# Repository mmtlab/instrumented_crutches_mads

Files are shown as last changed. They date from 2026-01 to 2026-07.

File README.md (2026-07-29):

# Instrumented Crutches

This repository contains an instrumented crutches system built on top of [MADS](https://github.com/pbosetti/MADS) (Multi-Agent Distributed System). 

**MADS** is a flexible, plugin-based framework for real-time data acquisition, processing, and distribution. It provides a modular architecture where different components (sources, filters, sinks) can be easily composed to create data processing pipelines. The system uses a publish/subscribe messaging pattern for inter-component communication and supports distributed deployments.

This project implements MADS plugins for collecting and processing data from instrumented crutches, including tip load cells, eye tracking, and coordination between multiple sensors. For more information about MADS, visit the [official documentation](https://mads-net.github.io/).

For the Instrumented Crutches documentation, visit the online [docs](https://mmtlab.github.io/instrumented_crutches_mads/index.html).

*Required MADS version: [2.0.0](https://github.com/pbosetti/MADS/releases/tag/v2.0.0)*
*Required cmake:run "sudo apt install cmake"*

## Installation

First, clone the repository:

```bash
git clone https://github.com/mmtlab/instrumented_crutches_mads.git
cd instrumented_crutches_mads
```

Each agent must be installed separately. See the `README.md` files inside each agent folder for details. 

**Important note**: Not all agents are required on both crutches. Compile only the agents needed for each crutch role:

- **Master crutch** (i.e. right): web_server, coordinator, status_handler, hdf5_writer, tip_loadcell, eye_tracker, ups, ppg
- **Slave crutch** (i.e. left): tip_loadcell, ups, ppg

### Settings file - mads.ini
Check the `mads.ini` configuration (i.e. the tip load cells' scaling factors) and run this command from the repository root if you want to overwrite the existing file:

```bash
sudo cp templates/mads.ini /usr/local/etc/
```

***Note***: provide write permissions to the data folder used by `web_server` and `hdf5_writer` (by default `web_server/data`), otherwise startup can fail.

If needed, fix ownership/permissions with:

```bash
sudo chown -R $USER:$USER ~/instrumented_crutches_mads/web_server/data
chmod -R u+rwX ~/instrumented_crutches_mads/web_server/data
```

### Enable services

Enable services according to the crutch role.

On the master crutch (i.e. right crutch), copy the service files to `/etc/systemd/system`:

```bash
sudo cp templates/mads-broker.service templates/mads-web_server.service templates/mads-coordinator.service templates/mads-status_handler.service templates/mads-hdf5_writer.service templates/mads-eye_tracker.service templates/mads-network_handler.service templates/right/mads-tip_loadcell.service templates/right/mads-handle_loadcell.service templates/right/mads-ups.service templates/right/mads-ppg.service /etc/systemd/system/
```

Then enable them:

```bash
sudo systemctl enable mads-broker.service mads-web_server.service mads-coordinator.service mads-status_handler.service mads-hdf5_writer.service mads-tip_loadcell.service mads-handle_loadcell.service mads-eye_tracker.service mads-network_handler.service mads-ups.service mads-ppg.service
```

On the slave crutch (i.e. left crutch), copy the service file to `/etc/systemd/system`:

```bash
sudo cp templates/left/mads-tip_loadcell.service templates/left/mads-handle_loadcell.service templates/left/mads-ups.service templates/left/mads-ppg.service /etc/systemd/system/
```
Then enable it:

```bash
sudo systemctl enable mads-tip_loadcell.service mads-handle_loadcell.service mads-ups.service mads-ppg.service
```

Use the pre-configured service files in `templates/left` and `templates/right` for the correct crutch side.

For the Python agent, check the paths in the service file and adapt them to the current configuration.

All enabled services start their agents automatically at boot.

### Configure network

On the master crutch Raspberry Pi, create a Wi-Fi hotspot:

```bash
sudo nmcli device wifi hotspot ssid <network-name> password <network-password>
```

On the slave crutch Raspberry Pi, configure the connection to that hotspot and enable auto-connect:

```bash
sudo nmcli connection modify <connection-name> connection.autoconnect yes
sudo nmcli connection up <connection-name>
```

### Configure NTP synchronization

Install chrony by running:

```bash
sudo apt install chrony
```

Copy the configuration file to `/etc/chrony`:

```bash
sudo cp templates/chrony.conf /etc/chrony/
```

Enable and restart the service:

```bash
sudo systemctl enable chrony
sudo systemctl restart chrony
```

Run this NTP configuration on both crutches.

***Important note***: the NTP configuration file (`chrony.conf`) uses `10.42.0.1` as the default server IP.
Check the master crutch hotspot IP address and update the file accordingly before copying it to `/etc/chrony/`.

## Acquisition board case
You can find the acquisition board case STL files in the `templates/case` folder for 3D printing.

## Architecture

```mermaid
---
config:
  layout: elk
  theme: neo-dark
  look: neo
---
flowchart BT
 subgraph master["Master"]
        web_server["Web Server"]
        coordinator["Coordinator"]
        status_handler["Status Handler"]
        hdf5_writer["HDF5 Writer"]
        eye_tracker["Eye Tracker"]
        hdf5[("HDF5 file")]
        m_ups["UPS"]
  end
 subgraph slave["Crutch"]
        s_ups["UPS"]
        s_tip_loadcell["Tip Loadcell"]
        s_handle_loadcell["Handle Loadcell"]
        s_ppg["PPG"]
        s_sync_handler["Sync Handler"]
  end
    web_server -- ws_command --> coordinator
    coordinator -- command --> status_handler & hdf5_writer & eye_tracker
    status_handler -- status --> web_server
    m_ups -- ups --> status_handler
    hdf5_writer -- data --> hdf5
    hdf5_writer -- hdf5_writer --> status_handler
    eye_tracker -- pupil_neon --> status_handler & hdf5_writer
    coordinator -. command .-> s_tip_loadcell & s_handle_loadcell & s_ppg
    s_tip_loadcell -. tip_loadcell .-> status_handler & hdf5_writer
    s_handle_loadcell -. handle_loadcell .-> status_handler & hdf5_writer
    s_ups -. ups .-> status_handler
    s_ppg -. ppg .-> status_handler & hdf5_writer
```

Each instrumented crutch runs on a Raspberry Pi Zero 2 W and uses MADS agents for sensing, control, and communication.
In this architecture, some agents run only on the master crutch, while others run on both crutches.

Master-only services
- **Web Server**: provides the Record/View/Download UI and sends control commands.
- **Coordinator**: receives web commands and orchestrates acquisition lifecycle across agents.
- **Status Handler**: aggregates startup/health/error/shutdown events and publishes system status.
- **HDF5 Writer**: logs incoming topics into structured HDF5 files for each acquisition.
- **Eye Tracker (Pupil Neon)**: manages discovery/connection/recording and publishes sync statistics.

Services deployed on both crutches
- **Tip Loadcell**: acquires axial load from the tip sensor.
- **Handle Loadcell**: acquires multi-channel handle forces.
- **PPG**: acquires photoplethysmography data.
- **UPS**: publishes battery and power metrics.

## Usage

Recommended workflow (Web interface):

1. Power on the master crutch (default: **right**) and wait for services to start.
2. Connect a PC/tablet/smartphone to the master hotspot.
3. Open `http://10.42.0.1:8000` in your browser (the **Record** page).
4. In the **Status** panel, click **Update Datetime** to immediately sync the master date/time.
5. Power on the slave crutch (left): it will auto-connect to the hotspot and sync time via NTP after about 1-2 minutes.
6. In the **Status** panel, verify that the main nodes are reachable (tip/handle/ppg, logger, coordinator; eye-tracker if used).
7. Run calibration in **Calibration** with the **Calibrate** button and check updated values/indicators. **Note:** keep the crutch lifted off the ground and do not press the handle, otherwise the offset calibration will be invalid.
8. (Optional) In the **Eye-tracker** section, click **Connect** and verify the status becomes *Connected*. **Note:** for discovery to work, the Pupil Neon must be paired with its smartphone, and must be connected to the same network as the master crutch.
9. Fill in **Test Configuration** fields (Subject ID, Session ID, Height, Weight, Crutch Height).
10. (Optional) Add notes in **Comments**.
11. (Optional) Click **Condition** and select the current condition.
12. Click **Start** to begin recording.
13. During acquisition, monitor **Status** and confirm services/sensors are in a recording-consistent state.
14. If the condition changes during the test, use **Condition** again. The timestamp of each new condition is recorded.
15. Click **Stop** to end the acquisition.

Note: each acquisition is assigned an incremental ID (shown as `Recording ID`).

After recording:

- **View Data**: select Subject, Session, and Recording to display charts.
- **Download**: download CSV files (`force_ID.csv` and `info_ID.csv`).

Only master (no crutch)
sudo cp templates/mads-broker.service templates/mads-web_server.service templates/mads-coordinator.service templates/mads-status_handler.service templates/mads-hdf5_writer.service templates/mads-eye_tracker.service templates/mads-network_handler.service /etc/systemd/system/

sudo systemctl enable mads-broker.service mads-web_server.service mads-coordinator.service mads-status_handler.service mads-hdf5_writer.service mads-eye_tracker.service mads-network_handler.service

mads-filter hdf5_writer.plugin -b -o folder_path="C:\mirrorworld\instrumented_crutches_mads\web_server\data"

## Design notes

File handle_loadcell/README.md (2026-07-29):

# handle_loadcell plugin for MADS

This is a Filter plugin for [MADS](https://github.com/MADS-NET/MADS). 

<provide here some introductory info>

*Required MADS version: 2.0.0.*

## Supported platforms

Currently, the supported platforms are:

* **Debian** 
* **Windows (debug)**

## Installation

Debian:

```bash
cmake -Bbuild -DCMAKE_INSTALL_PREFIX="$(mads -p)"
cmake --build build
sudo cmake --install build
```

Windows:

```powershell
cmake -Bbuild -DCMAKE_INSTALL_PREFIX="$(mads -p)"  -DRASPBERRYPI_PLATFORM=OFF
cmake --build build --config Release -t install
```

## INI settings

The plugin supports the following settings in the INI file:

```ini
# execution command example:
# mads-filter handle_loadcell -o side=left --dont-block
[handle_loadcell]
sub_topic = ["coordinator"] # power_status is used to adapt the ADC's reference voltage in realtime reading from the "supply_voltage" field
pub_topic = "handle_loadcell"
period = 20
ref_voltage = 4.12
adc1_rate = 9 # ADS1263 rate index, default 9 = 1200 SPS, but raspberry can reach maximum 100Hz
side = "unknown" # used to select scaling factors
health_status_period = 500 # ms
# Adjust the input number with the connected loadcell's label
# Default is:
#  IN0, IN1, IN2, IN3, IN4, IN5, IN6, IN7 
# "up_front", "up_back", "right_front", "right_back", "left_front", "left_back","down_front", "down_back"
input_map = [[0, "up_front"], [1, "up_back"], [2, "right_front"], [3, "right_back"], [4, "left_front"], [5, "left_back"], [6, "down_front"], [7, "down_back"]]

[handle_loadcell.range_map]
left = [[0, 500.0], [1, 500.0], [2, 50.0], [3, 50.0], [4, 50.0], [5, 50.0], [6, 50.0], [7, 50.0]] # IN0, IN1, IN2, IN3, IN4, IN5, IN6, IN7
right = [[0, 500.0], [1, 500.0], [2, 50.0], [3, 50.0], [4, 50.0], [5, 50.0], [6, 50.0], [7, 50.0]] # IN0, IN1, IN2, IN3, IN4, IN5, IN6, IN7
```

All settings are optional; if omitted, the default values are used.

When `health_status_period` elapses, the plugin also publishes a `perf` block with:

- `adc_read_ms`: time spent in `ADS1263_GetAll(...)`
- `process_ms`: duration of a full `process()` call
- `cycle_ms`: time between successive completed `process()` calls
- `adc1_rate`: configured ADS1263 data rate index
- `channels`: number of channels read each cycle

## Executable demo

<Explain what happens if the test executable is run>

---

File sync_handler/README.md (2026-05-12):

# sync_handler plugin for MADS

This is a Filter plugin for [MADS](https://github.com/MADS-NET/MADS). 

<provide here some introductory info>

*Required MADS version: 2.0.0.*

## Supported platforms

Currently, the supported platforms are:

* **Debian** 

## Installation

Debian:

```bash
cmake -Bbuild -DCMAKE_INSTALL_PREFIX="$(mads -p)"
cmake --build build
sudo cmake --install build
```

## INI settings

The plugin supports the following settings in the INI file:

```ini
# execution command example:
# mads-filter sync_handler -o side=left -s tcp://10.42.0.1:9092
[sync_handler]
sub_topic = ["coordinator"]
pub_topic = "sync_handler"
health_status_period = 1000 # ms
queue_size = 1
```

All settings are optional; if omitted, the default values are used.

Operational constraints:

* `queue_size` must be set to `1`.
* The `-b` argument is not needed, because the synchronization check is only performed when a message is received from the `coordinator` topic.
* The NTP server and the `coordinator` must run on the same device, so the timestamp comparison is performed against a single local time source.

## Executable demo

<Explain what happens if the test executable is run>

---

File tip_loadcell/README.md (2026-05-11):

# loadcell plugin for MADS

This is a Filter plugin for [MADS](https://github.com/pbosetti/MADS). 

<provide here some introductory info>

*Required MADS version: [2.0.0](https://github.com/pbosetti/MADS/releases/tag/v2.0.0)*

## Supported platforms

Currently, the supported platforms are:

* **Debian** 
* **Windows**

## Installation

Install the HX711's library ([HX711](https://github.com/mrcghidelli/hx711.git))

```bash
sudo apt-get install -y liblgpio-dev

git clone https://github.com/mrcghidelli/hx711.git
cd hx711

make && sudo make install
```
You may need to run ldconfig at this point if you attempt to compile a program and libhx711 is not found.

Then install the MADS agent.

Raspberry:

```bash
cmake -Bbuild -DCMAKE_INSTALL_PREFIX="$(mads -p)"
cmake --build build
sudo cmake --install build
```

Windows (debug and develop):

```powershell
cmake -Bbuild -DCMAKE_INSTALL_PREFIX="$(mads -p)" -DRASPBERRYPI_PLATFORM=OFF
cmake --build build --config Release -t install
```

## INI settings

The plugin supports the following settings in the INI file:

```ini
# execution command example:
# mads-filter tip_loadcell.plugin -o side=left --dont-block
[tip_loadcell]
sub_topic = ["coordinator"]
pub_topic = "tip_loadcell"
datapin = 6
clockpin = 26
period = 5 # it must be lower than 10 ms otherwise the HX711 will enter power down mode, which causes a delay of ~100 ms when reading the next value (it wakes up and takes ~100 ms to stabilize the readings)
side = "unknown" # used to select scaling factor
health_status_period = 500 # ms

[tip_loadcell.scaling]
left = 1.0 # debug value
right = 1.2 # debug value

```

All settings are optional; if omitted, the default values are used.

**Note:** The HX711 sampling frequency must remain above 80 Hz to prevent power-down mode. We recommend setting the period to 5 ms.

## Executable demo

<Explain what happens if the test executable is run>

---

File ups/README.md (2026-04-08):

# UPS for MADS

This is a Python agent for [MADS](https://github.com/MADS-NET/MADS). 

<provide here some introductory info>

*Required MADS version: 2.0.0.*

## Supported platforms

Currently, the supported platforms are:

* **Debian / Raspberry Pi OS (I2C required)**

## Setup

```bash
# Enable I2C on Raspberry Pi first (raspi-config -> Interface Options -> I2C)

# System packages (Raspberry Pi / Debian)
sudo apt-get update
sudo apt-get install -y python3-pip python3-smbus i2c-tools

# Create and activate venv (recommended)
python -m venv venv
source venv/bin/activate  # On Windows: venv\Scripts\activate

# Install dependencies
pip install -r requirements.txt
```

**Dependencies:**
- smbus (provided by `python3-smbus`) or `smbus2` via pip fallback

## Run example

```bash
python ups.py -o side=right
```

Add `-s tcp:\\<broker-ip>:9092` to connect to a remote broker (default is `tcp:\\localhost:9092`).

The agent connects to MADS broker and publishes every `health_status_period` ms on `pub_topic`.
Each published message contains:

- `voltage`
- `current`
- `power`
- `percent`
- `remaining_battery_time`

`remaining_battery_time` is estimated with a linear fit over the last 60 seconds of battery percentage history, and is expressed in seconds. If the trend is flat/rising, the value is `null`.

## INI settings

The plugin supports the following settings in the INI file:

```ini
[ups]
pub_topic = "ups"
health_status_period = 500 # ms
i2c_bus = 1
i2c_address = 67 # decimal for 0x43
battery_empty_voltage = 3.0
battery_full_voltage = 4.2
```

`health_status_period` controls the publish period. Battery percentage and remaining time use `battery_empty_voltage` and `battery_full_voltage` for normalization.

All settings are optional; if omitted, the default values are used.

## Executable demo

<Explain what happens if the test executable is run>

---

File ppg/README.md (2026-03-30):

# UPS HAT for MADS

This is a Python agent for [MADS](https://github.com/MADS-NET/MADS). 

The source code to acquire from the MAX 30100 has been get from https://github.com/mfitzp/max30100.git

<provide here some introductory info>

*Required MADS version: 2.0.0.*

## Supported platforms

Currently, the supported platforms are:

* **Debian / Raspberry Pi OS (I2C required)**

## Setup

```bash
# Enable I2C on Raspberry Pi first (raspi-config -> Interface Options -> I2C)

# System packages (Raspberry Pi / Debian)
sudo apt-get update
sudo apt-get install -y python3-smbus i2c-tools

# Create and activate venv (recommended)
python -m venv venv
source venv/bin/activate  # On Windows: venv\Scripts\activate

# Install dependencies
pip install -r requirements.txt
```

**Dependencies:**
- smbus (provided by `python3-smbus`) or `smbus2` via pip fallback

## Run

```bash
python ppg.py
```

Add `-s tcp:\\<broker-ip>:9092` to connect to a remote broker (default is `tcp:\\localhost:9092`).

## INI settings

The plugin supports the following settings in the INI file:

```ini
[ppg]
sub_topic = ["coordinator"]
pub_topic = "ppg"
health_status_period = 500 # ms
period = 10 # ms, 100 Hz
side = "unknown"
```

All settings are optional; if omitted, the default values are used.

---

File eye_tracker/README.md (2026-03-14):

# Eye Tracker for MADS

This is a Python agent for [MADS](https://github.com/pbosetti/MADS) that integrates with Pupil Labs Neon eye trackers.

*Required MADS version: [2.0.0](https://github.com/pbosetti/MADS/releases/tag/v2.0.0)*

## Description

The `pupil_neon` agent enables data acquisition from Pupil Labs Neon eye tracking devices. It handles device discovery, connection management, recording control, and real-time synchronization monitoring.

## Features

- **Automatic Device Discovery**: Discovers Pupil Labs Neon devices on the local network
- **Recording Control**: Start/stop recordings with template-based metadata (subject ID, session ID, acquisition ID)
- **Condition Events**: Send labeled condition markers during recording for experimental protocols
- **Time Synchronization**: Estimates and publishes time offset and round-trip latency statistics
- **Health Monitoring**: Continuous connection health checks and status reporting
- **Agent Status Tracking**: Reports connection state and errors via MADS publish/subscribe

## Agent States

- **STARTUP**: Agent initializing
- **IDLE**: Connected to MADS, waiting for commands (no device connected)
- **CONNECTED**: Device connected and ready for recording
- **RECORDING**: Currently recording data
- **SHUTDOWN**: Agent shutting down

## Supported Commands

Commands are received via MADS topic and processed based on agent state:

| Command | State | Action |
|---|---|---|
| `pupil_neon_connect` | IDLE | Discover and connect to Pupil Neon device |
| `pupil_neon_disconnect` | CONNECTED, RECORDING | Stop recording (if active) and disconnect device |
| `start` | CONNECTED | Fill device template and start recording |
| `stop` | RECORDING | Stop recording and save data |
| `condition` | RECORDING | Send labeled condition marker (e.g., "trial_A.begin") |

## Published Data

The agent publishes the following information to the MADS topic:

```json
{
  "agent_status": "idle|connected|recording",
  "error": "error message (if any)",
  "time_offset_ms_mean": 0.5,
  "time_offset_ms_std": 0.2,
  "time_offset_ms_median": 0.4,
  "roundtrip_duration_ms_mean": 15.3,
  "roundtrip_duration_ms_std": 2.1,
  "roundtrip_duration_ms_median": 14.9
}
```

- **agent_status**: Current operational state
- **error**: Error message if connection is lost or operation fails
- **time_offset_ms_***: Estimated clock synchronization offset in milliseconds (mean, std, median)
- **roundtrip_duration_ms_***: Network round-trip latency statistics in milliseconds

## INI Settings

```ini
[pupil_neon]
sub_topic = ["coordinator"]
pub_topic = "pupil_neon"
health_status_period = 500 # ms
```

## Setup

```bash
# Create and activate venv (recommended)
python -m venv venv
source venv/bin/activate  # On Windows: venv\Scripts\activate

# Install dependencies
pip install -r requirements.txt
```

**Dependencies:**
- pupil-labs-realtime-api

## Run

```bash
python pupil_neon.py
```

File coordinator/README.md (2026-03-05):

# coordinator plugin for MADS

This is a Filter plugin for [MADS](https://github.com/pbosetti/MADS). 

*Required MADS version: [2.0.0](https://github.com/pbosetti/MADS/releases/tag/v2.0.0)*

## Supported platforms

Currently, the supported platforms are:

* **Debian** 
* **Windows (debug only)**

## Installation

Debian:

```bash
cmake -Bbuild -DCMAKE_INSTALL_PREFIX="$(mads -p)"
cmake --build build
sudo cmake --install build
```

Windows (debug only):

```powershell
cmake -Bbuild -DCMAKE_INSTALL_PREFIX="$(mads -p)" -DRASPBERRYPI_PLATFORM=OFF
cmake --build build --config Release -t install
```

## INI settings

The plugin supports the following settings in the INI file:

```ini
# execution command example:
# mads-filter coordinator -b
[coordinator]
sub_topic = ["ws_command"]
pub_topic = "coordinator"
period = 10
health_status_period = 500 # ms
```

**Note**: This agent must run in non-blocking mode. Use the `-b` or `--dont-block` argument when running it.

---

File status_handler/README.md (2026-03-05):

# error_handler plugin for MADS

This is a Filter plugin for [MADS](https://github.com/pbosetti/MADS). 

*Required MADS version: [2.0.0](https://github.com/pbosetti/MADS/releases/tag/v2.0.0)*

## Supported platforms

Currently, the supported platforms are:

* **Debian**
* **Windows (debug)**

## Installation

Debian:

```bash
cmake -Bbuild -DCMAKE_INSTALL_PREFIX="$(mads -p)"
cmake --build build
sudo cmake --install build
```

Windows (debug):

```powershell
cmake -Bbuild -DCMAKE_INSTALL_PREFIX="$(mads -p)"
cmake --build build --config Release -t install
```

## INI settings

The plugin supports the following settings in the INI file:

```ini
# execution command example:
# mads-filter status_handler
[status_handler] 
sub_topic = ["agent_event", "coordinator", "hdf5_writer", "tip_loadcell", "handle_loadcell", "imu", "pupil_neon"] # add other relevant topics to monitor (startup events, error events and shutdown events from all agents are automatically published to "agent_event" topic)
pub_topic = "status"
unreachable_agent_timeout = 3000 # ms
debug = false

```

---

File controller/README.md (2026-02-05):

# controller plugin for MADS

This is a Filter plugin for [MADS](https://github.com/MADS-NET/MADS). 

<provide here some introductory info>

*Required MADS version: 1.4.0.*

## Supported platforms

Currently, the supported platforms are:

* **Linux** 
* **MacOS**
* **Windows**

## Installation

Linux and MacOS:

```bash
cmake -Bbuild -DCMAKE_INSTALL_PREFIX="$(mads -p)"
cmake --build build
sudo cmake --install build
```

Windows:

```powershell
cmake -Bbuild -DCMAKE_INSTALL_PREFIX="$(mads -p)"
cmake --build build --config Release
cmake --install build --config Release
```

## INI settings

The plugin supports the following settings in the INI file:

```ini
[controller]
# Describe the settings available to the plugin
```

All settings are optional; if omitted, the default values are used.

## Executable demo

<Explain what happens if the test executable is run>

---

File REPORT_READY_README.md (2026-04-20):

# Instrumented Crutches - Test and System Report Template

Document version: 1.0
Project: Instrumented Crutches (MADS-based)

===============================================================================
1) DOCUMENT CONTROL
===============================================================================
Report title:
Author:
Date:
Revision:
Test environment (lab/clinical):
Related ticket/issue references:

===============================================================================
2) EXECUTIVE SUMMARY
===============================================================================
This document describes the Instrumented Crutches system, including software
architecture, installation procedure, operational workflow, and data acquisition
session results. The system is based on the MADS framework and a master/slave
architecture over two instrumented crutches.

Session objective:
Main outcome:
Key critical issues:
Next actions:

===============================================================================
3) SYSTEM OVERVIEW
===============================================================================
The system acquires biomechanical and physiological data from two instrumented
crutches, with optional eye-tracking integration (Pupil Neon) for combined
movement and visual-behavior analysis.

Key points:
- Real-time multi-sensor acquisition.
- Centralized coordination through MADS broker.
- Structured HDF5 logging.
- Web interface for start/stop, calibration, annotations, and status.

Roles:
- Master crutch (typically right): hosts web server, coordinator, status handler,
  hdf5 writer, eye tracker, and part of the sensors.
- Slave crutch (typically left): acquires and publishes sensor streams.

Communication:
- Publish/subscribe over MADS topics.

===============================================================================
4) TECHNICAL ARCHITECTURE
===============================================================================
Main agents (master only):
- web_server: UI and API for session management.
- coordinator: command orchestration and acquisition state management.
- status_handler: agent status/health aggregation.
- hdf5_writer: data persistence to HDF5 files.
- pupil_neon: eye-tracker integration.

Agents on both crutches:
- tip_loadcell: tip force acquisition.
- handle_loadcell: multi-channel handle force acquisition.
- ppg: photoplethysmography signal (IR/RED).
- ups: power and battery telemetry.

Simplified data flow:
1. web_server sends commands.
2. coordinator propagates commands to agents.
3. sensors publish streams.
4. status_handler produces aggregated system status.
5. hdf5_writer stores streams into HDF5.

===============================================================================
5) INSTALLATION SUMMARY
===============================================================================
Minimum prerequisites:
- Raspberry Pi Zero 2 W (or equivalent)
- Raspberry Pi OS
- MADS >= 2.0.0
- Python >= 3.9

Main setup steps:
1. Clone the repository.
2. Install/build required agents for master and slave.
3. Configure mads.ini.
4. Install and enable systemd services.
5. Configure network (master hotspot + slave auto-connect).
6. Configure time synchronization (chrony) on both nodes.

Important operational notes:
- Verify write permissions on the data folder used by web_server/hdf5_writer.
- Verify hotspot IP consistency with NTP configuration.
- Use side-specific service templates (left/right).

===============================================================================
6) USER OPERATION WORKFLOW
===============================================================================
Recommended workflow:
1. Power on master and wait for services startup.
2. Connect client device (PC/tablet/smartphone) to master hotspot.
3. Open the Record page (default: http://10.42.0.1:8000).
4. Run Update Datetime from the Status panel.
5. Power on slave and wait for network/time alignment.
6. Verify reachability of main nodes in Status.
7. Run calibration (crutch lifted, no force on handle).
8. (Optional) Connect eye-tracker.
9. Fill Test Configuration.
10. (Optional) Add comments and condition.
11. Start recording (Start).
12. Monitor system status during test.
13. Update condition if needed during acquisition.
14. Stop recording (Stop).
15. Visualize/download post-session data.

Post-recording outputs:
- Data visualization.
- CSV export (force_ID.csv, info_ID.csv).
- Session HDF5 file.

===============================================================================
7) DATA AND OUTPUTS
===============================================================================
Main data types:
- Tip loadcell forces.
- Handle loadcell forces (multi-channel).
- PPG (IR/RED).
- Agent status and health.
- UPS telemetry (voltage/current/power/percent/remaining time).
- Session events/metadata (condition, comments, session IDs).

Persistence format:
- HDF5 with topic/keypath-based structure.

Session identifiers:
- Subject ID
- Session ID
- Incremental Recording ID

===============================================================================
8) TEST SESSION DETAILS (TO BE FILLED)
===============================================================================
Subject ID:
Session ID:
Recording ID:
Master side:
Slave side:
Eye-tracker used (YES/NO):
Operator:
Test duration:

Configured parameters:
- Subject height:
- Subject weight:
- Crutch height:
- Initial condition:

Event timeline:
- T0 system startup:
- T1 calibration:
- T2 start recording:
- T3 condition change (if any):
- T4 stop recording:

===============================================================================
9) HEALTH CHECK RESULTS
===============================================================================
Agent reachability outcome:
- coordinator:
- status_handler:
- hdf5_writer:
- tip_loadcell (master/slave):
- handle_loadcell (master/slave):
- ppg (master/slave):
- ups (master/slave):
- pupil_neon (if used):

Detected errors:
Applied mitigations:
Final health outcome:

===============================================================================
10) ISSUES, RISKS, AND LIMITATIONS
===============================================================================
Open issues:
1.
2.
3.

Known risks:
- Time drift if NTP is not correctly aligned.
- Invalid calibration if performed under applied load.
- Hotspot network instability in noisy radio environments.

Session limitations:

===============================================================================
11) CONCLUSIONS
===============================================================================
Final summary:

Decision (PASS/FAIL/PASS WITH NOTES):

Recommended follow-up actions:
1.
2.
3.

===============================================================================
12) APPENDIX - QUICK REFERENCES
===============================================================================
Project documentation:
- docs/index.html
- docs/installation.html
- docs/usage.html
- docs/architecture.html

Agent READMEs:
- web_server/README.md
- coordinator/README.md
- status_handler/README.md
- hdf5_writer/README.md
- eye_tracker/README.md
- tip_loadcell/README.md
- handle_loadcell/README.md
- ppg/README.md
- ups/README.md

===============================================================================
END OF TEMPLATE
===============================================================================

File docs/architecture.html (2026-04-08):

# System Architecture

The system is organized around two crutches connected through the MADS broker. The master crutch hosts the control and logging services, while both crutches run the sensing agents that publish data to the network.

## Overview

Each crutch is based on a Raspberry Pi Zero 2 W and runs a small set of MADS agents. The master side coordinates the acquisition workflow, stores data, and exposes the web interface. The slave side focuses on local sensing and publishes the same acquisition streams so the master can merge them into a single recording.

## Role Split

- Master-only services: Web Server, Coordinator, Status Handler, HDF5 Writer, Eye Tracker.
- Services on both crutches: Tip Loadcell, Handle Loadcell, PPG, UPS.

## System Diagram

Instrumented Crutches architecture diagram

Open diagram in a new tab

## Data Flow

The Web Server issues commands to the Coordinator through the MADS broker. The Coordinator drives the sensing agents, the Status Handler reports the live health of the system, and the HDF5 Writer persists the data streams that are later consumed by the visualization and download tools.

## Agent Details

Each agent is shown in its own transposed table for readability.

### Master-only agents

web_server
Agent type | Filter
Role | FastAPI backend and UI host. Manages acquisitions, test metadata, comments, conditions, plotting, and CSV download.
Sub topics | status
Pub topics | ws_command
JSON output format | {"command": "...", ...} with allowed values for command: start, stop, set_offset, get_agents_status, datetime_update, condition, pupil_neon_connect, pupil_neon_disconnect

coordinator
Agent type | Filter
Role | Command router and state gate. Validates transitions and forwards normalized commands to all agents.
Sub topics | ws_command
Accepted command | start, stop, condition, datetime_update get_agents_status, set_offset pupil_neon_connect, pupil_neon_disconnect
Pub topics | coordinator
JSON output format | Command: {"command":..., "id"?:n, "label"?:s, "subject_id"?:n, "session_id"?:n} Heartbeat: {"agent_status":"idle|recording"}

status_handler
Agent type | Filter
Role | Status aggregator and normalizer. It merges agent events and health messages into a single stream and marks agents unreachable after a timeout.
Sub topics | agent_event coordinator ups hdf5_writer tip_loadcell handle_loadcell ppg pupil_neon
Accepted command | get_agents_status
Pub topics | status
JSON output format | {"status":{"source","level","status","message","side"?}}

hdf5_writer
Agent type | Filter
Role | HDF5 logger. During recording, appends configured keypaths to topic groups and finalizes files on stop.
Sub topics | coordinator tip_loadcell handle_loadcell ppg pupil_neon ups
Accepted command | start stop
Pub topics | hdf5_writer
JSON output format | Heartbeat: {"agent_status":"idle|recording"}

pupil_neon
Agent type | Filter
Role | Pupil Neon integration: device discovery/connection, recording control, condition events, and time-sync metrics.
Sub topics | coordinator
Accepted command | pupil_neon_connect start condition stop pupil_neon_disconnect
Pub topics | pupil_neon
JSON output format | Heartbeat: {"agent_status":...,"error"?:...} Sync: time_offset_ms_*, roundtrip_duration_ms_*, (*mean, median, and std)

### Agents deployed on both crutches

tip_loadcell
Agent type | Filter
Role | HX711-based tip force acquisition with side-specific scale and offset handling.
Sub topics | coordinator
Accepted command | start stop set_offset
Pub topics | tip_loadcell
JSON output format | Recording: {"force":n,"side":"left|right"} Heartbeat: {"agent_status":"idle|recording","side":"left|right"} Offset: {"info":{"offset":{"value":n,"test":n}},"side":"left|right"}

handle_loadcell
Agent type | Filter
Role | 8-channel ADS1263 handle-force acquisition with channel map, range conversion, and offset calibration.
Sub topics | coordinator
Accepted command | start stop set_offset
Pub topics | handle_loadcell
JSON output format | Recording: {"force":{"sensor_label":...},"side":"left|right"} Offset: {"info":{"offset":{"value":{"sensor_label":...},"test":{"sensor_label":...}}},"side":"left|right"} Heartbeat: {"agent_status":"idle|recording","side":"left|right"} Sensor labels are up_front, up_back, right_front, right_back, left_front, left_back, down_front, down_back.

ppg
Agent type | Filter
Role | MAX30100-based PPG acquisition; publishes IR/RED samples while recording plus status heartbeat.
Sub topics | coordinator
Accepted command | start stop
Pub topics | ppg
JSON output format | Heartbeat: {"agent_status":"idle|recording","side":"left|right"} Samples: {"ir":n,"red":n,"side":"left|right"}

ups
Agent type | Source
Role | INA219 power monitor; computes battery percentage and estimated remaining time and publishes periodic telemetry.
Pub topics | ups
JSON output format | {"agent_status":"idle","side":"left|right","info":{"voltage","current","power","percent","remaining_battery_time"}}

© 2024-2026 Instrumented Crutches. Built on MADS framework.

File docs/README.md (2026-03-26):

# Instrumented Crutches Documentation

This directory contains the complete HTML documentation for the Instrumented Crutches system, automatically generated for deployment via GitHub Pages.

Documentation will be available at: `https://mmtlab.github.io/instrumented_crutches_mads/`

## Local Development

To view documentation locally during development:

```bash
cd docs
python -m http.server 8080
# Visit http://localhost:8080 in your browser
```

## File Structure

```
docs/
├── index.html              # Landing page
├── architecture.html      # System design
├── installation.html       # Installation guide
├── usage.html             # Operating manual
├── style.css             # Unified styling
└── .nojekyll             # Disable Jekyll processing
```

### Adding New Pages

1. Create new HTML file in `docs/`
2. Copy header/nav structure from existing page
3. Add link to nav bar in all pages
4. Update `.active` class on new page's nav link

## Version

- **Last Updated:** March 2026
- **Built for:** MADS 2.0.0+
- **Target Platform:** Raspberry Pi Zero 2 W

---

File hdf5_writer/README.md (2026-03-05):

# hdf5 plugin for MADS

This is a Filter plugin for [MADS](https://github.com/pbosetti/MADS). 

This plugin saves the incoming data into a [HDF5](https://www.hdfgroup.org/solutions/hdf5/) file. It is designed to work with the MADS framework, allowing users to store data in a structured format that is efficient for both storage and retrieval.

Data are stored in a hierarchical structure, similar to a filesystem, which allows for easy organization and access. The plugin supports various data types and can handle large datasets efficiently.

Data are stored in **groups** and **datasets**. Each group can contain multiple datasets. Each MADS topic is stored in a separate group. Withion the group, only the data within a given *keypath* is stored, by appending.

Suppose that the incoming data contains the following key-value pairs:

```json
{
  "key1": "value1",
  "key2": {
    "subkey1": 10,
    "subkey2": [1.0, 2.3, 3.7]
  },
  "key3": "value4"
}
```

and we specify that the followings keypaths are to be stored:

```ini
keypaths = ["key1", "key2.subkey1", "key2.subkey2", "key3"]
```

then the dataset `key1` will contain a column vector of strings, the dataset `key2.subkey1` will contain a column vector of integers, the dataset `key2.subkey2` will contain a table of doubles, and the dataset `key3` will contain a column vector of strings.

The keypath separator is `.` by default, but it can be changed in the INI file (note that `/` is not a valid separator).

An health status message is published if requested, when receiving a "health_status" command in the "command" input. 

*Required MADS version: [2.0.0](https://github.com/pbosetti/MADS/releases/tag/v2.0.0)*

## Supported platforms

Currently, the supported platforms are:

* **Debian** 
* **Windows (debug)**

## Installation

Debian:

```bash
cmake -Bbuild -DCMAKE_INSTALL_PREFIX="$(mads -p)"
cmake --build build
sudo cmake --install build
```

Windows (debug):

```powershell
cmake -Bbuild -DCMAKE_INSTALL_PREFIX="$(mads -p)"
cmake --build build --config Release -t install
```

## INI settings example for Instrumented Crutches

The plugin supports the following settings in the INI file:

```ini
# --------------------------------
# HDF5 Loggers
# --------------------------------

# execution command examples:
# mads-sink hdf5_writer -b 
# Note: if you add more than one keypath for the "coordinator" topic, it is not guaranteed that the fields have the same size (it depends if the "A" field is always present when the "B" field is present, etc)
[hdf5_writer]
sub_topic = ["coordinator", "tip_loadcell", "handle_loadcell", "imu", "pupil_neon"]
pub_topic = "hdf5_writer"
folder_path = "~/instrumented_crutches_mads/web_server/data" # adapt the path to your installation
keypath_sep = "."
keypaths = {"coordinator" = ["label"], "tip_loadcell" = ["side", "force"], "handle_loadcell" = ["side", "force"], "imu" = ["side", "ax", "ay", "az", "gx", "gy", "gz", "mx", "my", "mz"], "pupil_neon" = ["time_offset_ms_mean", "time_offset_ms_std", "time_offset_ms_median", "roundtrip_duration_ms_mean", "roundtrip_duration_ms_std", "roundtrip_duration_ms_median"]}
health_status_period = 500 # ms
```

The keypaths `timecode` and `timestamp` are always added to the list of keypaths, even if not specified in the INI file. Since `timecode` and `timestamp` are always logged, make sure that if you publish a message for one crutch, you also fill the other crutch's field with a NaN. This ensures that every row in the timestamp dataset has a corresponding row in the force dataset.

**Note**: This agent must run in non-blocking mode. Use the `-b` or `--dont-block` argument when running it.
**Note**: if you add more than one keypath for the "coordinator" topic, it is not guaranteed that the fields have the same size (it depends if the "A" field is always present when the "B" field is present, etc)

# HDF5 Tools

The install command also installs some of the HDf5 tools, notably:

* `h5ls`: lists the contents of an HDF5 file
* `h5watch`: watches an HDF5 file for changes
* `h5stat`: displays statistics about an HDF5 file

---

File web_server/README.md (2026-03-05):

# Web Server

This is a Python agent for [MADS](https://github.com/pbosetti/MADS). 

*Required MADS version: [2.0.0](https://github.com/pbosetti/MADS/releases/tag/v2.0.0)*

FastAPI-based web interface for instrumented crutches data acquisition and visualization system.
Designed for Raspberry Pi Zero 2 W - plain HTTP, no authentication, maximum simplicity.

## Features

- **Recording Control**: Start/stop acquisition with real-time timer
- **Data Visualization**: Interactive charts with Chart.js showing left/right crutch force data
- **Calibration**: Set sensor offset via web interface
- **MADS Integration**: Sends commands via `mads` to control MADS plugins
- **HDF5 Data Storage**: Reads recorded data from HDF5 files 

## Architecture

The system integrates with MADS :
- Sends `start`/`stop`/`set_offset` commands via `mads` to topic `ws_command`
- Reads HDF5 files generated by `hdf5_writer` plugin
- Supports independent left/right crutch data 

## Setup

```bash
# Create and activate venv (recommended)
python -m venv venv
source venv/bin/activate  # On Windows: venv\Scripts\activate

# Install dependencies
pip install -r requirements.txt
```

**Dependencies:**
- FastAPI + Uvicorn (web server)
- h5py (HDF5 file reading)
- python-dateutil (timestamp parsing)

## Run

```bash
python web_server.py
```

Then open `http://10.42.0.1:8000` (or `http://localhost:8000` if not connected to the `crutchwifi` network) in your browser.

## Data Storage

- **Acquisitions Index**: `data/index.json` - metadata for all recordings
- **HDF5 Files**: `data/acq_N.h5` - all agents data

## Notes

- **Plain HTTP only** - no HTTPS, no authentication
- **Local network only** - designed for trusted local environment
- **Acquisition IDs**: Sequential integers (acq_1, acq_2, etc.)
- **No database** - uses JSON index file for simplicity

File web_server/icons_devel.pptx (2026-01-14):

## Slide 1

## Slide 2

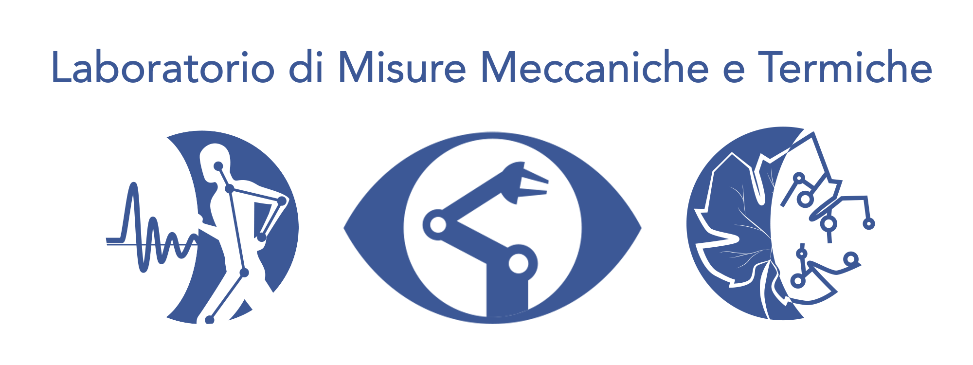
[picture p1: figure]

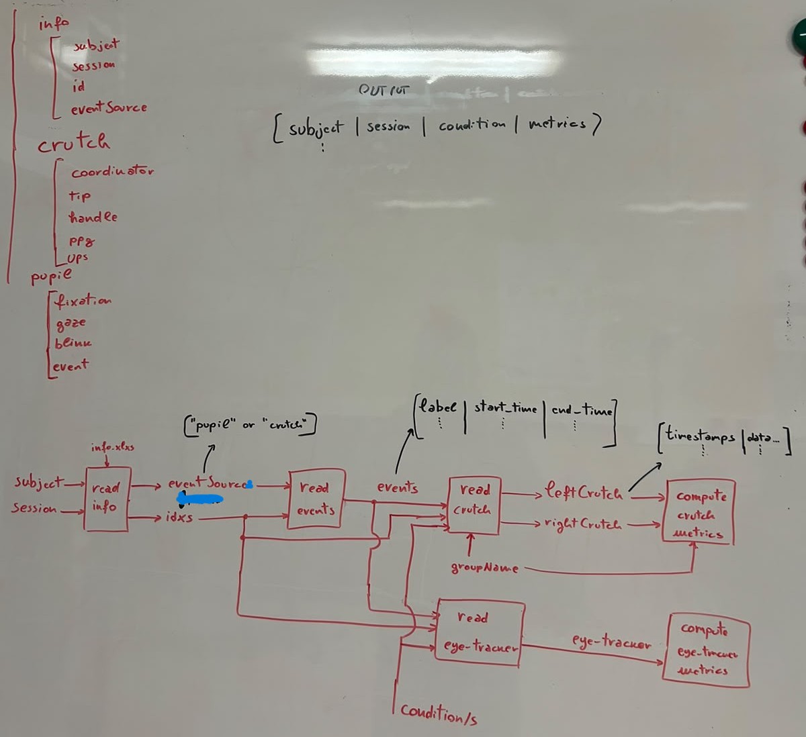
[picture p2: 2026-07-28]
analysis/matlab/schema.jpeg

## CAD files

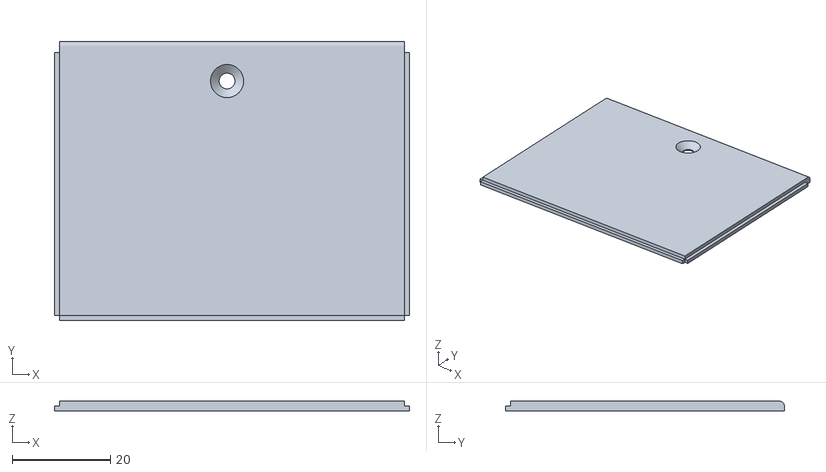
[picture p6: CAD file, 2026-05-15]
templates/stl/case/raspi02_escape_v2 - lid.stl
72.1 x 56.6 x 2.00

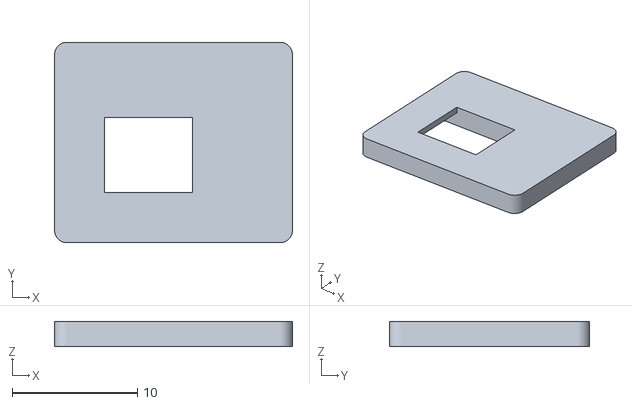
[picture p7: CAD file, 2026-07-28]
templates/stl/handle/ppg_cover - left_ppg.stl
19.0 x 16.0 x 2.00

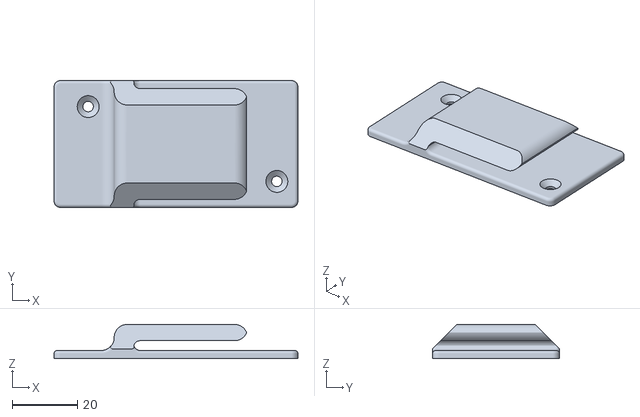
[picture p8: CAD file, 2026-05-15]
templates/stl/case/raspi02_escape_master - lid.stl
75.0 x 39.0 x 10.5

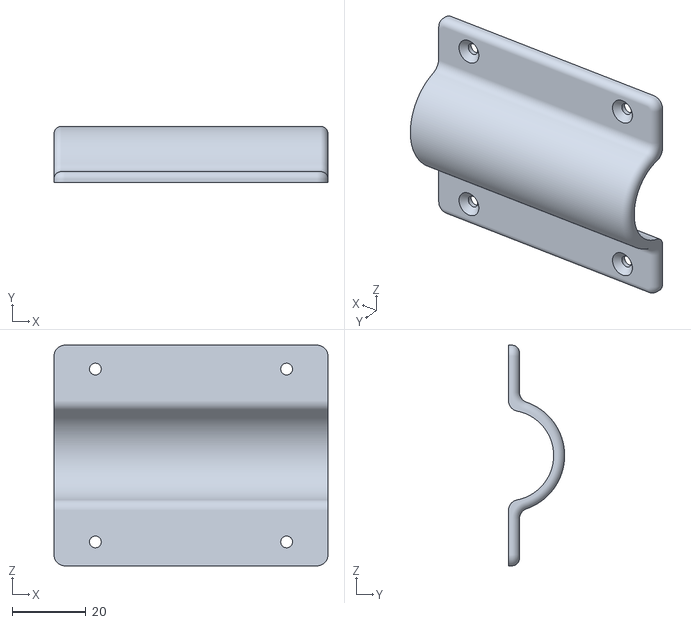
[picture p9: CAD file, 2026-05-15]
templates/stl/case/raspi02_escape_v2 - clamp.stl
74.5 x 15.3 x 60.0

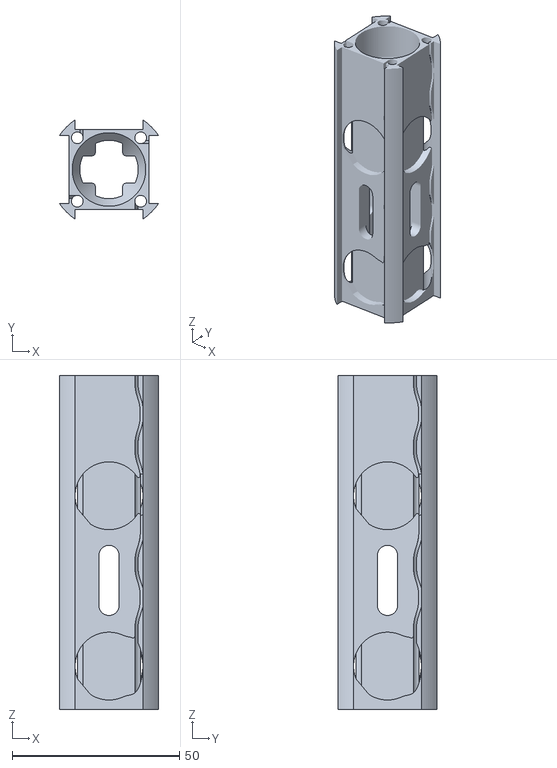
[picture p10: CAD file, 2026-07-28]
templates/stl/handle/06_Impugnatura_06_25feb2026.STL
29.6 x 29.6 x 100.0

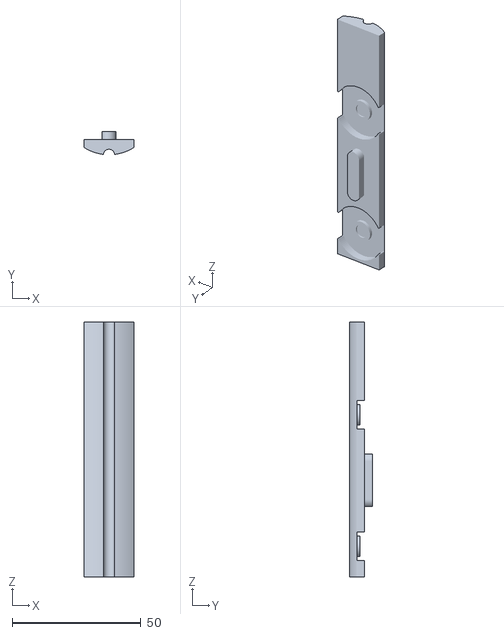
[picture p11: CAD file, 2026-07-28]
templates/stl/handle/06_Pulsante_06_20feb2026.STL
19.4 x 8.87 x 99.0

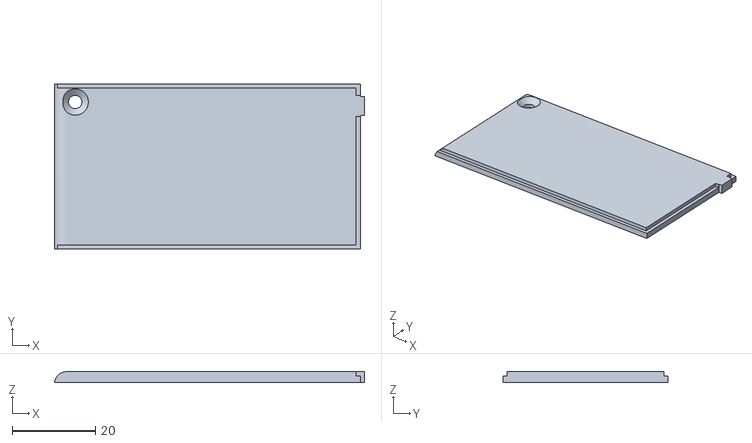
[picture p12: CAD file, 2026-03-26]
templates/stl/case/raspi02_lid.stl
74.5 x 39.6 x 2.60

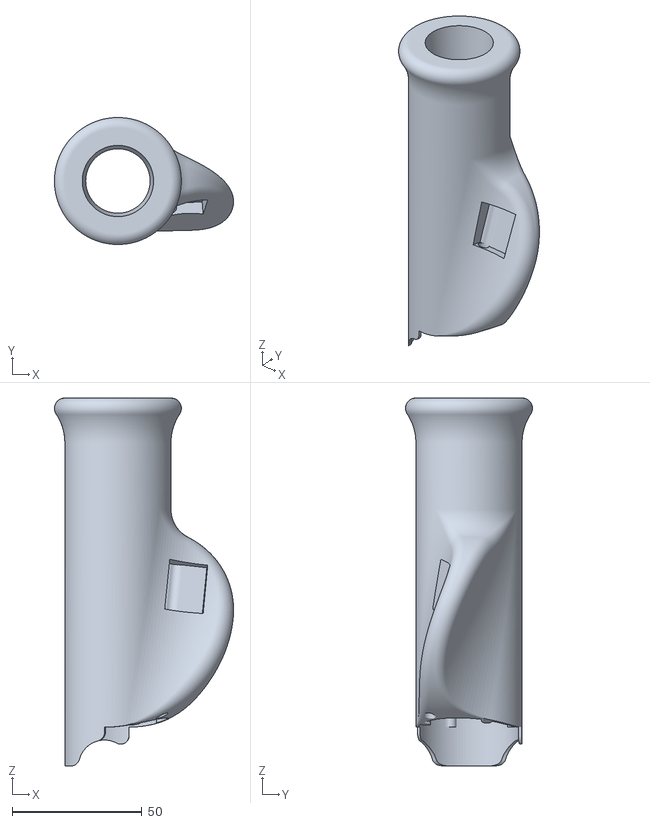
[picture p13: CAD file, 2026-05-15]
templates/stl/handle/Manopola_24aprile2026_02_R185.STL
69.1 x 49.0 x 142.0

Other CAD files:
templates/stl/handle/ppg_cover - right_ppg.stl
templates/stl/case/raspi02_clamp.stl
templates/stl/handle/SpecchiaturaManopola_24aprile2026_02_R1851.STL

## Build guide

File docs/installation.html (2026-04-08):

# Installation Guide

This page summarizes the installation flow from the main repository README and adds direct links to each agent README.

## 1. Clone Repository

git clone https://github.com/mmtlab/instrumented_crutches_mads.git
cd instrumented_crutches_mads

Required MADS version: 2.0.0 or above.

## 2. Build and Install Agents

Each agent is installed separately. Build only the services required by each crutch role:

- Master crutch (right): web_server, coordinator, status_handler, hdf5_writer, eye_tracker, tip_loadcell, handle_loadcell, ppg, ups
- Slave crutch (left): tip_loadcell, handle_loadcell, ppg, ups

## 3. Configure mads.ini

Review settings (for example loadcell scaling values), then copy the template configuration:

sudo cp templates/mads.ini /usr/local/etc/

Ensure write permissions for the data folder used by web_server and hdf5_writer (default: web_server/data):

sudo chown -R $USER:$USER ~/instrumented_crutches_mads/web_server/data
chmod -R u+rwX ~/instrumented_crutches_mads/web_server/data

## 4. Enable Services

Copy and enable systemd service files according to the crutch role.

### Master Crutch (Right)

sudo cp templates/mads-broker.service templates/mads-web_server.service templates/mads-coordinator.service templates/mads-status_handler.service templates/mads-hdf5_writer.service templates/mads-eye_tracker.service templates/mads-network_handler.service templates/right/mads-tip_loadcell.service templates/right/mads-handle_loadcell.service templates/right/mads-ups.service templates/right/mads-ppg.service /etc/systemd/system/
sudo systemctl enable mads-broker.service mads-web_server.service mads-coordinator.service mads-status_handler.service mads-hdf5_writer.service mads-tip_loadcell.service mads-handle_loadcell.service mads-eye_tracker.service mads-network_handler.service mads-ups.service mads-ppg.service

### Slave Crutch (Left)

sudo cp templates/left/mads-tip_loadcell.service templates/left/mads-handle_loadcell.service templates/left/mads-ups.service templates/left/mads-ppg.service /etc/systemd/system/
sudo systemctl enable mads-tip_loadcell.service mads-handle_loadcell.service mads-ups.service mads-ppg.service

Use the service templates in templates/left and templates/right for correct side-specific setup.

## 5. Configure Network

On the master Raspberry Pi, create a hotspot:

sudo nmcli device wifi hotspot ssid <network-name> password <network-password>

On the slave Raspberry Pi, configure auto-connect to that hotspot:

sudo nmcli connection modify <connection-name> connection.autoconnect yes
sudo nmcli connection up <connection-name>

## 6. Configure Time Synchronization (Chrony)

sudo apt install chrony
sudo cp templates/chrony.conf /etc/chrony/
sudo systemctl enable chrony
sudo systemctl restart chrony

Run this on both crutches. The default chrony.conf uses 10.42.0.1 as NTP server; update it if your hotspot IP differs.

## Agent README Links

Use the following README files for per-agent build and runtime details:

- Main repository README
- web_server/README.md
- coordinator/README.md
- status_handler/README.md
- hdf5_writer/README.md
- eye_tracker/README.md
- tip_loadcell/README.md
- handle_loadcell/README.md
- ppg/README.md
- ups/README.md

## Case Files

Acquisition board case STL files are available in templates/case.

© 2024-2026 Instrumented Crutches. Built on MADS framework.

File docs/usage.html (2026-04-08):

# Usage Manual

## Setup and Recording

# | Action

1 | Power on the master crutch (default: right) and wait for services to start.
2 | Connect a PC/tablet/smartphone to the master hotspot.
3 | Open http://10.42.0.1:8000 in your browser (the Record page).
4 | In the Status panel, click Update Datetime to immediately sync the master date/time.
5 | Power on the slave crutch (left): it will auto-connect to the hotspot and sync time via NTP after about 1-2 minutes.
6 | In the Status panel, verify that the main nodes are reachable (tip/handle/ppg, logger, coordinator; eye-tracker if used).
7 | Run calibration in Calibration with the Calibrate button and check updated values/indicators. Note: keep the crutch lifted off the ground and do not press the handle, otherwise the offset calibration will be invalid.
8 | (Optional) In the Eye-tracker section, click Connect and verify the status becomes Connected. Note: for discovery to work, the Pupil Neon must be paired with its smartphone, and must be connected to the same network as the master crutch.
9 | Fill in Test Configuration fields (Subject ID, Session ID, Height, Weight, Crutch Height).
10 | (Optional) Add notes in Comments.
11 | (Optional) Click Condition and select the current condition.
12 | Click Start to begin recording. Note: the condition can be changed during acquisition; the timestamp of each new condition is recorded.
13 | During acquisition, monitor Status and confirm services/sensors are in a recording-consistent state.
14 | If the condition changes during the test, use Condition again.
15 | Click Stop to end the acquisition.

Note: each acquisition is assigned an incremental ID (shown as Recording ID).

## After Recording

- View Data: select Subject, Session, and Recording to display charts.
- Download: download CSV files (force_ID.csv and info_ID.csv).

Note: View data and download are still under development.

© 2024-2026 Instrumented Crutches. Built on MADS framework.

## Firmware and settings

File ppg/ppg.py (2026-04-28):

import argparse
import subprocess
import sys
import os
import time
from enum import Enum
from typing import Optional

import max30100


# locate mads python package
mads_path = subprocess.check_output(["mads", "-p"], text=True).strip()
sys.path.append(os.path.join(mads_path, "python"))

from mads_agent import Agent, MessageType


class AgentStatus(Enum):
    STARTUP = 0
    SHUTDOWN = 1
    IDLE = 2
    RECORDING = 3


class PpgAgent:
    def __init__(self, broker_url="tcp://localhost:9092", options="side=unknown"):
        self.agent = Agent("ppg", broker_url)
        self.agent.set_id("ppg")
        self.agent.set_settings_timeout(2000)
        if self.agent.init() != 0:
            sys.stderr.write("Cannot contact broker\nCheck if the broker is running and the URL is correct.\n Check the mads.ini file.\n")
            sys.exit(1)
        self.agent.connect()

        settings = self.agent.settings()

        self.pub_topic = settings.get("pub_topic", "ppg")
        self.sub_topic = settings.get("sub_topic", ["coordinator"])
        if isinstance(self.sub_topic, str):
            self.sub_topic = [self.sub_topic]
        elif not isinstance(self.sub_topic, list):
            self.sub_topic = [str(self.sub_topic)]

        self.health_status_period = int(settings.get("health_status_period", 500))
        self.period = int(settings.get("period", 1))
        print(f"PPG agent settings: pub_topic={self.pub_topic}, sub_topic={self.sub_topic}, health_status_period={self.health_status_period}ms, period={self.period}ms, options={options}")

        # Keep receive non-blocking enough to honor publish timers.
        receive_timeout_ms = max(10, min(self.health_status_period, self.period, 100))
        self.agent.set_receive_timeout(receive_timeout_ms)

        self.side = settings.get("side", "unknown")
        if options != "side=unknown":
            options_dict = dict(opt.split("=", 1) for opt in options.split(",") if "=" in opt)
            self.side = options_dict.get("side", "unknown")

        self.sensor_mode = max30100.MODE_HR
        self.sensor_sample_rate = 100
        self.sensor_led_current_red = 50.0
        self.sensor_led_current_ir = 50.0
        self.sensor_pulse_width = 1600
        self.enable_spo2 = True
        self.max_buffer_len = 1

        # Lazily initialize sensor only on start command.
        self.mx30 = None
        self._probe_sensor()

        # agent status tracking
        self.agent_status = AgentStatus.STARTUP

        self._accept_all_topics = "" in self.sub_topic
        self._sub_topics_set = {str(topic) for topic in self.sub_topic if topic != ""}

        time.sleep(0.5)  # Give some time for the agent to be fully ready

        # After publishing startup status, we can set the status to IDLE to indicate we are ready for commands
        self.agent_status = AgentStatus.IDLE
        print("PPG agent started")

    def _publish_metrics_and_status(self, ir=None, red=None, error: Optional[str] = None, include_status: bool = False):
        
        payload = {}

        if include_status:
            payload["agent_status"] = self.agent_status.name.lower()

        if ir is not None and red is not None:
            payload["ir"] = ir
            payload["red"] = red

        if error is not None:
            payload["error"] = error

        if payload:
            # add side only when something is actually published
            payload["side"] = self.side

            self.agent.publish(payload, self.pub_topic)

    def start_recording(self):
        if self.agent_status == AgentStatus.RECORDING:
            return
        self._start_sensor()
        print("PPG sensor recording started")
        self.agent_status = AgentStatus.RECORDING

    def stop_recording(self):
        self._stop_sensor()
        print("PPG sensor recording stopped")
        self.agent_status = AgentStatus.IDLE

    def _start_sensor(self):
        if self.mx30 is not None:
            return
        self.mx30 = max30100.MAX30100(
            mode=self.sensor_mode,
            sample_rate=self.sensor_sample_rate,
            led_current_red=self.sensor_led_current_red,
            led_current_ir=self.sensor_led_current_ir,
            pulse_width=self.sensor_pulse_width,
            max_buffer_len=self.max_buffer_len
        )
        if self.enable_spo2:
            self.mx30.enable_spo2()

    def _probe_sensor(self):
        probe = None
        try:
            probe = max30100.MAX30100(
                mode=self.sensor_mode,
                sample_rate=self.sensor_sample_rate,
                led_current_red=self.sensor_led_current_red,
                led_current_ir=self.sensor_led_current_ir,
                pulse_width=self.sensor_pulse_width,
                max_buffer_len=self.max_buffer_len
            )
            probe.enable_spo2()
            probe.get_part_id()
        finally:
            if probe is not None:
                try:
                    probe.shutdown()
                except Exception:
                    pass
            self.mx30 = None

    def _stop_sensor(self):
        if self.mx30 is None:
            return
        try:
            self.mx30.shutdown()
        finally:
            self.mx30 = None

    def _process_command(self, topic, message):
        if not self._accept_all_topics and topic not in self._sub_topics_set:
            return

        if not isinstance(message, dict):
            return

        cmd = message.get("command")
        if not cmd:
            return

        cmd = str(cmd).lower()
        if cmd == "start":
            try:
                self.start_recording()
            except Exception as exc:
                self.agent_status = AgentStatus.IDLE
                self._publish_metrics_and_status(ir=None, red=None, error=f"Failed to start sensor: {exc}")
        elif cmd == "stop":
            try:
                self.stop_recording()
            except Exception as exc:
                self._publish_metrics_and_status(ir=None, red=None, error=f"Failed to stop sensor: {exc}")

    def run(self):
        """Main run loop: publish status/metrics and react to commands."""

        health_period_s = max(self.health_status_period, 1) / 1000.0
        sample_period_s = max(self.period, 1) / 1000.0

        
        now = time.monotonic()
        next_health_ts = now + health_period_s
        next_sample_ts = now + sample_period_s

        try:
            while True:
                now = time.monotonic()

                # check if it's time to publish health status (even if we have no new sensor data, to indicate we are alive and our status)
                include_status = now >= next_health_ts
                if include_status:
                    next_health_ts = now + health_period_s

                if self.agent_status == AgentStatus.RECORDING and now >= next_sample_ts:
                    try:
                        if self.mx30 is None:
                            raise RuntimeError("Sensor not initialized")
                        self.mx30.read_sensor()

                        self._publish_metrics_and_status(ir=self.mx30.ir, red=self.mx30.red, error=None, include_status=include_status)
                    except Exception as exc:
                        self._publish_metrics_and_status(ir=None, red=None, error=str(exc), include_status=include_status)
                    next_sample_ts = now + sample_period_s

                elif self.agent_status != AgentStatus.RECORDING and include_status:
                    self._publish_metrics_and_status(ir=None, red=None, error=None, include_status=include_status)


                msg_type = self.agent.receive()
                if msg_type != MessageType.NONE:
                    topic, message = self.agent.last_message()
                    self._process_command(topic, message)


        except KeyboardInterrupt:
            pass
        finally:
            self.agent_status = AgentStatus.SHUTDOWN
            try:
                self._stop_sensor()
                self._publish_metrics_and_status(ir=None, red=None, error="Agent shutting down")
            except Exception:
                pass
            try:
                self.agent.disconnect()
            except Exception:
                pass


def main():
    parser = argparse.ArgumentParser(description="PPG MADS agent")
    parser.add_argument("-s", "--server", default="tcp://localhost:9092",
                        help="Broker URL (default: tcp://localhost:9092)")
    parser.add_argument("-o", "--options", default="side=unknown",
                        help="crutch side (default: side=unknown)")
    args = parser.parse_args()

    agent = None
    last_error = None
    exit_code = 0
    try:
        agent = PpgAgent(broker_url=args.server, options=args.options)
        agent.run()
    except KeyboardInterrupt:
        exit_code = 0
    except Exception as exc:
        last_error = exc
        sys.stderr.write(f"Error running PpgAgent: {exc}\n")
        exit_code = 1
    finally:
        if agent is not None:
            try:
                if last_error is not None:
                    agent._publish_metrics_and_status(ir=None, red=None, error=str(last_error))
            except Exception:
                pass
        sys.exit(exit_code)


if __name__ == "__main__":
    main()

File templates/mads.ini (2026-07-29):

#   ____                                      
#  / ___|___  _ __ ___  _ __ ___   ___  _ __  
# | |   / _ \| '_ ` _ \| '_ ` _ \ / _ \| '_ \ 
# | |__| (_) | | | | | | | | | | | (_) | | | |
#  \____\___/|_| |_| |_|_| |_| |_|\___/|_| |_|
# 


[agents]
# Settings shared by all agents
frontend_address = "tcp://localhost:9090"
backend_address = "tcp://localhost:9091"
settings_address = "tcp://localhost:9092"
compress = true
timecode_fps = 25


#  __  __                   _ _ _   _     _      
# |  \/  | ___  _ __   ___ | (_) |_| |__ (_) ___ 
# | |\/| |/ _ \| '_ \ / _ \| | | __| '_ \| |/ __|
# | |  | | (_) | | | | (_) | | | |_| | | | | (__ 
# |_|  |_|\___/|_| |_|\___/|_|_|\__|_| |_|_|\___|
#                                                

[broker]
frontend_address = "tcp://*:9090"
backend_address = "tcp://*:9091"
settings_address = "tcp://*:9092"


[logger]
mongo_uri = "mongodb://localhost:27017"
mongo_db = "mads_test"
# sub_topic = ["logger", "metadata", "rfid", "skeleton", "platform", "image", "agent_event", "bridge", "perf_assess"]
# or, subscribe to all topics:
sub_topic = [""]
max_length = 75
initially_paused = false


[bridge]
# default publish topic (if not passed via CLI)
sub_topic = ["publish"]
pub_topic = "bridge"


[feedback]
# Subscribes to ALL topics
sub_topic = ["status"]
print_width = 0
indent_width = 2

[metadata]
# Topic to publish to (single string!)
pub_topic = "metadata"


[perf_assess]
pub_topic = "perf_assess"

[publish]
pub_topic = "publish"

[dealer]
sub_topic = ["publish", "spawner"]
pub_topic = "dealer"
dealer_address = "tcp://*:9093"

[worker]
pub_topic = "worker"
dealer_address = "tcp://localhost:9093"


#  ____  _             _           
# |  _ \| |_   _  __ _(_)_ __  ___ 
# | |_) | | | | |/ _` | | '_ \/ __|
# |  __/| | |_| | (_| | | | | \__ \
# |_|   |_|\__,_|\__, |_|_| |_|___/
#                |___/             
#

[echoj]
# Topic to publish to (single string!)
pub_topic = "echoj"
sub_topic = ["rfid"]


[clock]
# Topic to publish to (single string!)
pub_topic = "clock"
period = 200


[monitor]
sub_topic = [""]
col_widths = [18, 15, 15]
yellow = 0.1
red = 0.1
silent = true

# --------------------------------
# --------------------------------
# Instrumented Crutches Agents
# --------------------------------
# --------------------------------

# --------------------------------
# Controllers
# --------------------------------

[web_server]
sub_topic = ["status"]
pub_topic = "ws_command"

# execution command example:
# mads-filter coordinator -b
[coordinator]
sub_topic = ["ws_command"]
pub_topic = "coordinator"
period = 10
health_status_period = 500 # ms


# execution command example:
# mads-filter status_handler
[status_handler]
sub_topic = ["agent_event", "coordinator", "ups", "sync_handler", "hdf5_writer", "tip_loadcell", "handle_loadcell", "ppg", "pupil_neon"] # add other relevant topics to monitor (startup events, error events and shutdown events from all agents are automatically published to "agent_event" topic)
pub_topic = "status"
unreachable_agent_timeout = 6000 # ms
debug = true

# execution command example:
# source venv/bin/activate
# python ups.py
[ups]
pub_topic = "ups"
health_status_period = 5000 # ms
i2c_bus = 1
i2c_address = 67 # decimal for 0x43
battery_empty_voltage = 3.3
battery_full_voltage = 4.0

# execution command example:
# mads-filter sync_handler -o side=left 
[sync_handler]
sub_topic = ["coordinator"]
pub_topic = "sync_handler"
health_status_period = 1000 # ms
queue_size = 1

# --------------------------------
# Sensors
# --------------------------------

# execution command example:
# mads-filter tip_loadcell -o side=left -b
[tip_loadcell]
sub_topic = ["coordinator"]
pub_topic = "tip_loadcell"
datapin = 6
clockpin = 26
period = 5
side = "unknown" # used to select scaling factor
health_status_period = 500 # ms

[tip_loadcell.scaling]
left = 5.6401 # debug value
right = 5.5891 # debug value


# execution command example:
# mads-filter handle_loadcell -o side=left --dont-block
[handle_loadcell]
sub_topic = ["coordinator"] # power_status is used to adapt the ADC's reference voltage in realtime reading from the "supply_voltage" field
pub_topic = "handle_loadcell"
period = 10
ref_voltage = 4.12
adc1_rate = 9 # ADS1263 rate index, default 9 = 1200 SPS, but raspberry can reach maximum 100Hz
side = "unknown" # used to select scaling factors
health_status_period = 500 # ms
# Adjust the input number with the connected loadcell's label
# Default is:
#  IN0, IN1, IN2, IN3, IN4, IN5, IN6, IN7 
# "up_front", "up_back", "right_front", "right_back", "left_front", "left_back","down_front", "down_back"
[handle_loadcell.input_map]
left = [[0, "up_front"], [1, "up_back"], [2, "down_front"], [3, "down_back"], [4, "int_front"], [5, "int_back"], [6, "ext_front"], [7, "ext_back"]]
right = [[0, "up_front"], [1, "up_back"], [2, "down_front"], [3, "down_back"], [4, "ext_front"], [5, "ext_back"], [6, "int_front"], [7, "int_back"]]
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

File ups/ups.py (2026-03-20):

import argparse
import os
import subprocess
import sys
import time
from collections import deque

try:
    import smbus
except ImportError:
    import smbus2 as smbus


# locate mads python package
mads_path = subprocess.check_output(["mads", "-p"], text=True).strip()
sys.path.append(os.path.join(mads_path, "python"))

from mads_agent import Agent, MessageType


# Config Register (R/W)
_REG_CONFIG = 0x00
# SHUNT VOLTAGE REGISTER (R)
_REG_SHUNTVOLTAGE = 0x01
# BUS VOLTAGE REGISTER (R)
_REG_BUSVOLTAGE = 0x02
# POWER REGISTER (R)
_REG_POWER = 0x03
# CURRENT REGISTER (R)
_REG_CURRENT = 0x04
# CALIBRATION REGISTER (R/W)
_REG_CALIBRATION = 0x05


class BusVoltageRange:
    RANGE_16V = 0x00
    RANGE_32V = 0x01


class Gain:
    DIV_1_40MV = 0x00
    DIV_2_80MV = 0x01
    DIV_4_160MV = 0x02
    DIV_8_320MV = 0x03


class ADCResolution:
    ADCRES_9BIT_1S = 0x00
    ADCRES_10BIT_1S = 0x01
    ADCRES_11BIT_1S = 0x02
    ADCRES_12BIT_1S = 0x03
    ADCRES_12BIT_2S = 0x09
    ADCRES_12BIT_4S = 0x0A
    ADCRES_12BIT_8S = 0x0B
    ADCRES_12BIT_16S = 0x0C
    ADCRES_12BIT_32S = 0x0D
    ADCRES_12BIT_64S = 0x0E
    ADCRES_12BIT_128S = 0x0F


class Mode:
    POWERDOW = 0x00
    SVOLT_TRIGGERED = 0x01
    BVOLT_TRIGGERED = 0x02
    SANDBVOLT_TRIGGERED = 0x03
    ADCOFF = 0x04
    SVOLT_CONTINUOUS = 0x05
    BVOLT_CONTINUOUS = 0x06
    SANDBVOLT_CONTINUOUS = 0x07


class INA219:
    def __init__(self, i2c_bus=1, addr=0x43):
        self.bus = smbus.SMBus(i2c_bus)
        self.addr = addr

        self._cal_value = 0
        self._current_lsb = 0
        self._power_lsb = 0
        self.set_calibration_16V_5A()

    def read(self, address):
        data = self.bus.read_i2c_block_data(self.addr, address, 2)
        return (data[0] * 256) + data[1]

    def write(self, address, data):
        temp = [0, 0]
        temp[1] = data & 0xFF
        temp[0] = (data & 0xFF00) >> 8
        self.bus.write_i2c_block_data(self.addr, address, temp)

    def set_calibration_16V_5A(self):
        self._current_lsb = 0.1524
        self._cal_value = 26868
        self._power_lsb = 0.003048

        self.write(_REG_CALIBRATION, self._cal_value)

        self.bus_voltage_range = BusVoltageRange.RANGE_16V
        self.gain = Gain.DIV_2_80MV
        self.bus_adc_resolution = ADCResolution.ADCRES_12BIT_32S
        self.shunt_adc_resolution = ADCResolution.ADCRES_12BIT_32S
        self.mode = Mode.SANDBVOLT_CONTINUOUS
        self.config = (
            (self.bus_voltage_range << 13)
            | (self.gain << 11)
            | (self.bus_adc_resolution << 7)
            | (self.shunt_adc_resolution << 3)
            | self.mode
        )
        self.write(_REG_CONFIG, self.config)

    def get_shunt_voltage_mv(self):
        self.write(_REG_CALIBRATION, self._cal_value)
        value = self.read(_REG_SHUNTVOLTAGE)
        if value > 32767:
            value -= 65535
        return value * 0.01

    def get_bus_voltage_v(self):
        self.write(_REG_CALIBRATION, self._cal_value)
        self.read(_REG_BUSVOLTAGE)
        return (self.read(_REG_BUSVOLTAGE) >> 3) * 0.004

    def get_current_ma(self):
        value = self.read(_REG_CURRENT)
        if value > 32767:
            value -= 65535
        return value * self._current_lsb

    def get_power_w(self):
        self.write(_REG_CALIBRATION, self._cal_value)
        value = self.read(_REG_POWER)
        if value > 32767:
            value -= 65535
        return value * self._power_lsb


class UpsAgent:
    def __init__(self, broker_url="tcp://localhost:9092", options="side=unknown"):
        self.agent = Agent("ups", broker_url)
        self.agent.set_id("ups")
        self.agent.set_settings_timeout(2000)
        if self.agent.init() != 0:
            sys.stderr.write("Cannot contact broker\nCheck if the broker is running and the URL is correct.\n Check the mads.ini file.\n")
            sys.exit(1)
        self.agent.connect()

        settings = self.agent.settings()

        self.pub_topic = settings.get("pub_topic", "ups")
        self.health_status_period = int(settings.get("health_status_period", 500))
        self.i2c_bus = int(settings.get("i2c_bus", 1))
        self.i2c_address = int(settings.get("i2c_address", 0x43))
        self.empty_voltage = float(settings.get("battery_empty_voltage", 3.0))
        self.full_voltage = float(settings.get("battery_full_voltage", 4.2))

        self.side = "unknown"
        if options != "side=unknown":
            options_dict = dict(opt.split("=", 1) for opt in options.split(",") if "=" in opt)
            self.side = options_dict.get("side", "unknown")

        self.ina219 = INA219(i2c_bus=self.i2c_bus, addr=self.i2c_address)

        self._history = deque()
        self._last_publish_ts = 0.0
        self._last_debug_len = 0
        self._eta_ema_seconds = None

        # ETA stability tuning
        self._eta_min_samples = 8
        self._eta_min_window_s = 20.0
        self._eta_slope_deadband = 1e-4  # percent/second
        self._eta_jump_limit = 0.30      # max +/-30% change per update before smoothing
        self._eta_ema_alpha = 0.22       # lower = smoother
        self._eta_max_seconds = 72.0 * 3600.0

    def _compute_percent(self, voltage):
        span = self.full_voltage - self.empty_voltage
        if span <= 0:
            return 0.0
        p = (voltage - self.empty_voltage) / span * 100.0
        if p < 0.0:
            return 0.0
        if p > 100.0:
            return 100.0
        return p

    def _update_history(self, ts, percent):
        self._history.append((ts, percent))
        one_minute_ago = ts - 60.0
        while self._history and self._history[0][0] < one_minute_ago:
            self._history.popleft()

    def _median(self, values):
        if not values:
            return None
        sorted_vals = sorted(values)
        n = len(sorted_vals)
        mid = n // 2
        if n % 2 == 1:
            return sorted_vals[mid]
        return 0.5 * (sorted_vals[mid - 1] + sorted_vals[mid])

    def _linear_slope(self, xs, ys):
        n = len(xs)
        if n < 2:
            return None
        mean_x = sum(xs) / n
        mean_y = sum(ys) / n
        denom = sum((x - mean_x) ** 2 for x in xs)
        if denom <= 0:
            return None
        return sum((x - mean_x) * (y - mean_y) for x, y in zip(xs, ys)) / denom

    def _robust_slope(self, xs, ys):
        # Two-pass fit: OLS, reject large residuals via MAD, then OLS again.
        slope = self._linear_slope(xs, ys)
        if slope is None:
            return None

        n = len(xs)
        mean_x = sum(xs) / n
        mean_y = sum(ys) / n
        intercept = mean_y - slope * mean_x

        residuals = [y - (slope * x + intercept) for x, y in zip(xs, ys)]
        abs_residuals = [abs(r) for r in residuals]
        mad = self._median(abs_residuals)

        if mad is None or mad <= 1e-9:
            return slope
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

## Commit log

2026-01-14 Restructure project and add MADS plugins
    Moved web server and static files into a new web_server directory, updated requirements, and improved the web UI with calibration and timer features. Added controller and loadcell MADS filter plugins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
2026-01-14 Add test config and comments to acquisition workflow
    Enhanced the web interface and backend to support test configuration (patient, height, weight, crutch height) and comments for each acquisition. Updated control.html and control.js to provide collaps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
2026-01-14 Add condition selection and saving to acquisition UI
    Introduces a modal for selecting test conditions, loads condition options from a new conditions.json file, and allows users to save the selected condition to the current or most recent acquisition. U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
2026-01-14 Add PWB chart and % body weight force visualization
    Introduces Partial Weight Bearing (PWB) chart to the visualization page and updates force data to display as % body weight when available. Improves mobile responsiveness and UI for chart panels. The 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
2026-01-14 Show only completed acquisitions and improve error handling
    The acquisition list UI now displays only completed acquisitions and shows a message if none are available. The acquisition card layout is simplified, and the download button label is shortened. On the backend, error handling is improved for force CSV downloads by checking for missing or empty loadcell data, and legacy comment formats are handled gracefully in info CSV downloads.
2026-01-29 feat: Add error_handler plugin and integrate MADS agent
    - Introduced error_handler plugin for MADS with functionality to process and filter error messages.
    - Implemented a new CMakeLists.txt for building the error_handler plugin.
    - Created README.md for error_handler with installation instructions and supported platforms.
    - Added error_handler.cpp with logic to handle various error formats and maintain a buffer of status messages.
    - Updated web_server.py to initialize and manage a MADS agent for communication.
    - Enhanced control.js and control.html to improve user feedback and error handling in the web interface.
    - Modified loadcell.cpp and controller.cpp to refine command handling and error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
2026-01-30 feat: Enhance offset indicators with visual feedback for calibration results
2026-02-11 Refactor and enhance various components of the project
    - Updated controller to handle command IDs as integers instead of strings.
    - Revised HDF5 writer documentation to reflect changes in INI settings and keypaths.
    - Modified HDF5 writer to prepend "_acq_" to filenames for clarity.
    - Improved status handler to streamline offset message handling and reduce redundancy.
    - Enhanced tip loadcell to include timestamp in output JSON.
    - Updated conditions JSON to add new conditions and modify existing ones.
    - Changed control HTML to replace patient name input with subject and session ID inputs.
    - Adjusted control JavaScript to accommodate new subject and session ID fields.
    - Enhanced visualization H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
2026-02-18 feat: Add new CSV download endpoints for handle force, cardiac frequency, and eye tracker data
    - Implemented download_handle_force_csv to export handle force data as CSV.
    - Added download_cardiac_frequency_csv for exporting cardiac frequency data.
    - Created download_eye_tracker_csv to export eye tracker data with specific columns.
    - Enhanced existing download_force_csv and download_info_csv functions to include subject and session IDs in filenames.
    - Introduced a new endpoint to check available sensors for an acquisition.
    - Added functionality to download all available sensors in a ZIP file if total size exceeds 10MB.
    - Improved error handling and timestamp conversion for various data types.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
2026-02-26 Refactor and enhance MADS plugins and web server functionality
    - Removed the filter_template plugin as it was no longer needed.
    - Updated tip_loadcell plugin to improve command handling and status reporting.
    - Enhanced web server to request health status on page load and improved logging.
    - Introduced a new coordinator plugin for managing commands and agent status.
    - Added CMake configuration for the coordinator plugin.
    - Created a README for the coordinator plugin with installation instructions and settings.
    - Updated template_mads.ini to include new configurations for the coordinator and other agents.
    [template_mads.ini]
2026-03-02 feat: Update status_handler and hdf5_writer configurations to include additional topics and correct folder paths
    [mads.ini]
2026-03-04 Refactor and update MADS plugins and templates
    - Removed deprecated hdf5_writer_backup.cpp file.
    - Updated README.md files for error_handler, tip_loadcell, and web_server plugins to reflect correct MADS repository link and improved clarity.
    - Deleted unused mads.ini template file and replaced it with a new version containing updated configurations.
    - Added systemd service templates for various MADS components including tip_loadcell, broker, coordinator, eye_tracker, hdf5_writer, network_handler, status_handler, and web_server.
    - Adjusted parameters in the status_handler plugin to set debug to false by default.
    - Enhanced documentation and comments in service files for better understanding an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
    [mads.ini]
2026-03-05 feat: Update README files to link required MADS version and add Raspberry Pi platform option in CMakeLists.txt
2026-03-12 Add ADS1263 driver and software SPI support for load cell handling
    - Implemented sysfs_software_spi.h for software SPI communication.
    - Added ADS1263.c and ADS1263.h files for ADS1263 ADC driver functionality.
    - Created handle_loadcell.cpp to integrate load cell processing with ADS1263.
    - Established methods for initializing the ADC, configuring settings, and reading data.
    - Included error handling and debugging outputs for better traceability.
    [main.c]
2026-03-13 feat: Enhance Raspberry Pi support and add command handling for load cell plugin
2026-03-14 Add UPS HAT agent for battery monitoring and status reporting
    - Implemented a new Python agent for the UPS HAT to monitor battery metrics including voltage, current, power, and percentage.
    - Added functionality to estimate remaining battery time based on historical data.
    - Integrated with the MADS broker to publish health status messages at a configurable interval.
    - Enhanced the web server to display battery status and handle status for left and right crutches.
    - Updated the control panel UI to include battery indicators and handle status.
    - Refactored existing code to accommodate new battery and handle status updates.
    - Added new CSS styles for battery status display.
    - Created README docu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
    [ups_hat.py]
2026-03-16 feat: Refactor calibration section and enhance offset handling in control panel
2026-03-20 feat: Refactor PPG agent to lazily initialize sensor and enhance error handling
    [max30100.py, ppg.py]
2026-03-20 feat: Add UPS agent to MADS with I2C support and service files
    - Introduced a new UPS agent for MADS, which monitors battery metrics including voltage, current, power, and estimated remaining battery time.
    - Updated `mads.ini` to include UPS configuration settings and topics for publishing status.
    - Removed obsolete UPS HAT files and documentation.
    - Added systemd service files for both left and right UPS agents to facilitate easy deployment and management.
    - Created README and requirements files for the new UPS agent to guide setup and usage.
2026-03-20 Add documentation for Instrumented Crutches project
    - Created overview.html for project overview, including project description, component summary, data flow, and research context.
    - Added style.css for consistent styling across documentation pages.
    - Developed troubleshooting.html to provide a comprehensive troubleshooting guide covering startup issues, connectivity, sensor problems, web interface issues, performance, and data issues.
    - Implemented usage.html detailing the usage manual with quick start steps, pre-acquisition calibration, web interface guide, data acquisition process, and shutdown procedures.
2026-03-26 Refactor code structure for improved readability and maintainability
    [raspi02_lid.stl]
2026-03-26 feat: Add performance metrics for ADC read and processing times in loadcell plugin
2026-03-26 feat: Add architecture diagram to README and update STL file for acquisition board case
2026-03-30 feat: Update README and service files for handle loadcell; enhance battery status handling in code
2026-04-08 feat: Update usage documentation and examples; adjust battery status display precision
2026-04-08 Refactor documentation and improve installation guide
    - Updated architecture documentation with system diagram and data flow description.
    - Enhanced index page for clarity on master/slave architecture.
    - Expanded installation guide with detailed steps for cloning, building, and configuring agents.
    - Improved usage manual with a structured table for setup and recording steps.
    - Adjusted CSS for better responsiveness in cards grid.
    - Removed unnecessary performance metrics from handle_loadcell agent.
    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
    [raspi02_clamp.stl]
2026-04-29 Add initial configuration file for MADS agents
    - Created mads.ini to define settings for agents, broker, logger, and various components.
    - Configured addresses for frontend, backend, and settings.
    - Included topics for communication between agents and logging.
    - Defined parameters for sensors, controllers, and HDF5 loggers.
    [mads.ini]
2026-05-11 fix the power down mode of the HX711 sensor
    [mads.ini]
2026-05-13 feat: Update battery status handling to include external battery source
2026-05-15 Add new STL files for handle components
    - Added Manopola_24aprile2026_02_R185.STL
    - Added SpecchiaturaManopola_24aprile2026_02_R1851.STL
    [Manopola_24aprile2026_02_R185.STL, SpecchiaturaManopola_24aprile2026_02_R1851.STL, raspi02_clamp.stl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]
2026-05-21 feat: Enhance control UI with condition timers and update logic for condition handling
2026-05-22 feat: Enhance timing display for conditions and acquisitions; add condition timer and update logic
2026-05-22 feat: Update acquisition ID display logic to differentiate between current and next recording IDs
2026-07-29 fix timer errors
